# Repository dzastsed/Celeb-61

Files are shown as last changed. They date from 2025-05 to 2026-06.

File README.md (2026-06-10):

# Celeb-61 
*a nod towards Celeb-17 nickname of Makise Kurisu*

{D4E6624E-90EE-470E-BB59-F3589989F7F6}

Working beta version with 2025-05 board design. No more bodges!
# DISCLAIMER
This design is still a prototype, stuff may break and/or change. You've been warned.

## New features:

* usb-c to ttl adapter (optional)

* usb-c power supply (optional)

* better layout

* mounting screw holes

Preview pics 

{12444C88-0332-4251-8D5A-DB2188448844}

Bottom

{63C3DD92-8271-487E-8219-108E031BC739}

Top



Top, artwork edition (legacy design in `old project and gerbers (do not use)` folder)

# Schematic

{0ACC69AB-D940-442C-9313-E54FB51414F8}

# Firmware

Regular clock, and clock with scrambling code implemented are included `firmware` folder.

- Regular firmware:
Just does the clock function, and nothing more. It probably isn't even up to date with current board design. Not recommended to use.

- Scramlin' firmware:
Does character scramble every hour (after 30 seconds pass at 31 minute mark) to prevent cathode poisoning. Up to date. Use this firmware.

# Known issues

None so far?

# Setup guide

refer to [installation.md](https://github.com/dzastsed/Celeb-61/blob/main/installation.md)

# Parts list

refer to [parts.md](https://github.com/dzastsed/Celeb-61/blob/main/parts.md)

# Future improvements

ESP32 support - for wi-fi clock sync etc.

Diode on TTL module power rail to prevent powering it from secondary USB port (or complete removal of 2ndary USB port as this board can be powered by TTL module just fine).

Different board versions for different tube footprints.

A physical switch of some sort to turn the clock off while it's still plugged in

More covering for high voltage parts

# Credits

TheMobas0 - for help on making the scramble code

Greatsccott! - original board design

Elli - for drawing Makise Kurisu art

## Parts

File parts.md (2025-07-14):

# Parts list

Parts required for base model are: (links are NOT affiliate)

* Arduino pro mini clone - must be 5V 16mhz variant - I bought them from [here](https://www.aliexpress.com/item/32966475348.html)

   *note - there are a couple of versions with different footprint, make sure you get the one I used in this project.*

* 4x CD66 or CD61 nixie tubes

* 4x binary to decimal converter ICs (K155ID1, SN74141N and similar)

* 4x 20K 0.4W resistors

* 4x 0603 100nF capacitors

* 2x 0603 10uF capacitors

* High-voltage power supply capable of reaching 170v - I used [these](https://www.aliexpress.com/item/1005005994400583.html)

* 5V power supply capable of pushing roughly 2 amps. (10W total)

* DS1307 RTC - I purchased mine from [here](https://www.aliexpress.com/item/1005007091017702.html)

  *note - DS3231 module is also supported, but make sure you desolder one resistor (documented [here](https://lastminuteengineers.com/ds3231-rtc-arduino-tutorial/)) if you choose to use a non-rechargeable battery. I also recommend to use this one instead because it keeps the time better due to having an integrated thermometer.*

Optional extras but highly recommended:

* CH9340C TTL board - will allow easy reprogramming without soldering - I purchased mine [here](https://www.aliexpress.com/item/4001214247042.html)

* Type-C breakout board - I purchased mine [here](https://www.aliexpress.com/item/1005006846325447.html)

* A simple tactile switch - Used for easy chip reset, can be either harvested or simply purchased, I bought them [here](https://www.aliexpress.com/item/1005004159746274.html)

* M3 Motherboard standoff kit - Purely cosmetic, can be used together with another spare board to make a good platform to stand on. [link](https://www.aliexpress.com/item/1005007498157463.html)

* 16 pin socket - HIGHLY recommended, because bin2dec converters can be faulty and it's really painful to desolder if that's the case. [link](https://www.aliexpress.com/item/1005003744699628.html)

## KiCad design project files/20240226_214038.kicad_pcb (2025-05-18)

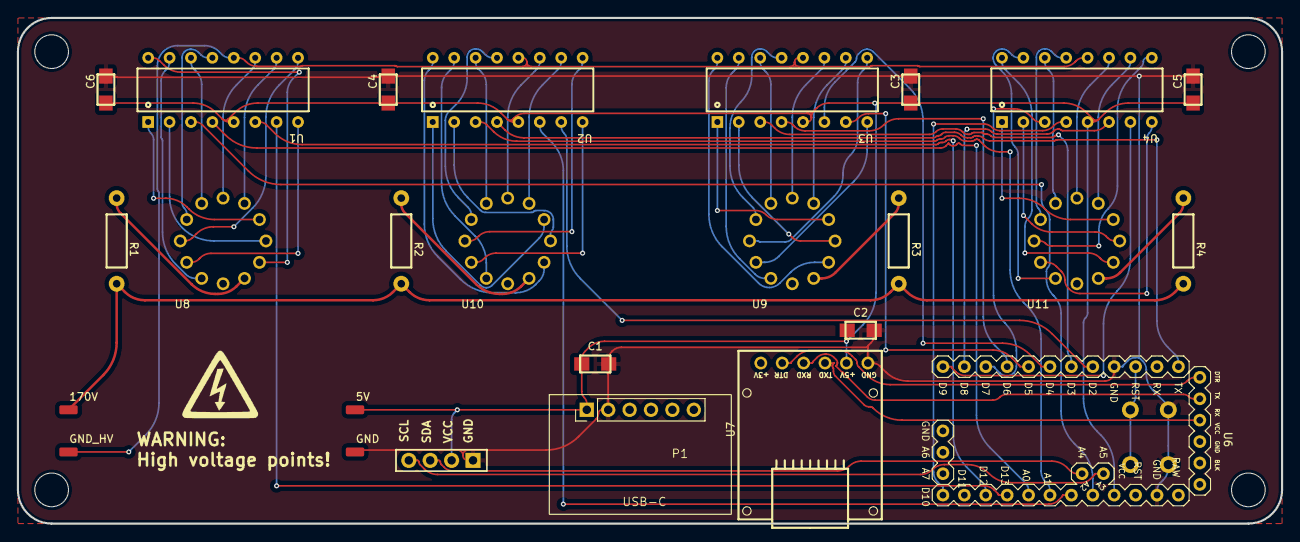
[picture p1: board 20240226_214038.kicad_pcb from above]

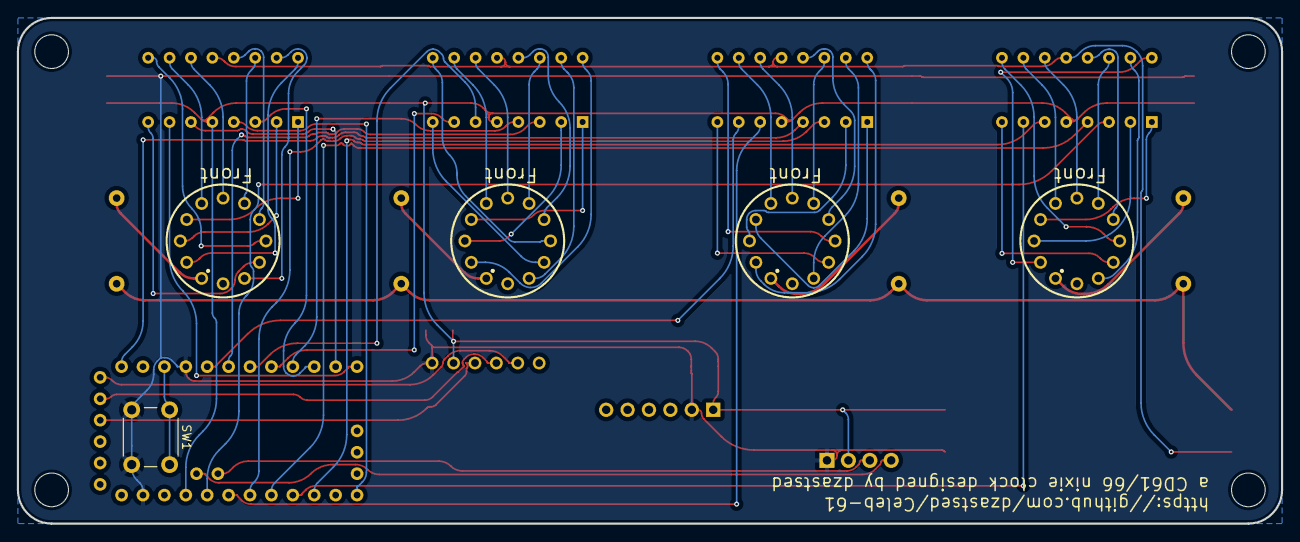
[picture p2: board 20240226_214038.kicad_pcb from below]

Board: 2 copper layers, 150.0 x 60.0 mm, 27 parts (5 on the bottom side), 70 nets.

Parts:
5V: 5V; SOLDERPAD
170V: 170V; SOLDERPAD
C1, C2: 10uF; CAPACITOR-SMD-1206
C3, C4, C5, C6: 100nF; CAPACITOR-SMD-1206
CLK1: ZS_042/DS3231; ZS-042-DS3231
GND: GND; SOLDERPAD
GND_HV: GND_HV; SOLDERPAD
P1: USB_C_Plug_USB2.0; USBC breakout
R1, R2, R3, R4: 20k; AXIAL-0.4
SW1: SW_Push; SW_PUSH_6mm
U1, U2, U3, U4: K155ID1/SN74141; DIP16
U6: ARDUINO PRO-MINI COPY; ARDUINOPROMINI_ARDUINO_PRO_MINI
U7: USB_TO_TTL_CH340E
U8, U9, U10, U11: Nixie_Tube_CD66_Tomas5054; NEC_NIXIE_TUBE_CD66A_TOMAS5054

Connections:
170v: 170V.1, R1.2, R2.2, R3.2, R4.2
+5V: 5V.1, C1.1, C2.1, C3.2, C4.2, C5.2, C6.2, CLK1.3 (VCC), P1.1 (VBUS), U1.5 (VCC), U2.5 (VCC), U3.5 (VCC), U4.5 (VCC), U6.VCC, U7.5 (+5V)
A1: U3.3 (A), U6.D3
A2: U4.3 (A), U6.D7
A3: U1.3 (A), U6.A3
A4: U2.3 (A), U6.A1
B1: U3.6 (B), U6.D4
B2: U4.6 (B), U6.D8
B3: U1.6 (B), U6.D12
B4: U2.6 (B), U6.A2
C1: U3.7 (C), U6.D5
C2: U4.7 (C), U6.D9
C3: U1.7 (C), U6.D13
C4: U2.7 (C), U6.D2
D1: U3.4 (D), U6.D6
D2: U4.4 (D), U6.D10
D3: U1.4 (D), U6.A0
D4: U2.4 (D), U6.TX
GND: C1.2, C2.2, C3.1, C4.1, C5.1, C6.1, CLK1.4 (GND), GND.1, P1.2 (GND), SW1.2, U6.GND, U6.GND@1 (GND), U7.6 (GND)
GND_HV: GND_HV.1, U1.12 (GND), U2.12 (GND), U3.12 (GND), U4.12 (GND)
unnamed: R1.1, U8.A
unnamed: R2.1, U10.A
unnamed: R3.1, U9.A
unnamed: R4.1, U11.A
unnamed: SW1.1, U6.RST@1 (RST)
unnamed: U6.RX@1 (RXI), U7.4 (TXD)
unnamed: U6.TX@1 (TX0), U7.3 (RXD)
unnamed: U6.DTR, U7.2 (DTR)
SCL: CLK1.1 (SCL), U6.A5
SDA: CLK1.2 (SDA), U6.A4
U8-0: U1.16 (0), U8.(.) (K(.))
U8-1: U1.15 (1), U8.1 (K(1))
U8-2: U1.8 (2), U8.2 (K(2))
U8-3: U1.9 (3), U8.3 (K(3))
U8-4: U1.13 (4), U8.4 (K(4))
U8-5: U1.14 (5), U8.5 (K(5))
U8-6: U1.11 (6), U8.6 (K(6))
U8-7: U1.10 (7), U8.7 (K(7))
U8-8: U1.1 (8), U8.8 (K(8))
U8-9: U1.2 (9), U8.9 (K(9))
U9-0: U3.16 (0), U9.(.) (K(.))
U9-1: U3.15 (1), U9.1 (K(1))
U9-2: U3.8 (2), U9.2 (K(2))
U9-3: U3.9 (3), U9.3 (K(3))
U9-4: U3.13 (4), U9.4 (K(4))
U9-5: U3.14 (5), U9.5 (K(5))
U9-6: U3.11 (6), U9.6 (K(6))
U9-7: U3.10 (7), U9.7 (K(7))
U9-8: U3.1 (8), U9.8 (K(8))
U9-9: U3.2 (9), U9.9 (K(9))
U10-0: U2.16 (0), U10.(.) (K(.))
U10-1: U2.15 (1), U10.1 (K(1))
U10-2: U2.8 (2), U10.2 (K(2))
U10-3: U2.9 (3), U10.3 (K(3))
U10-4: U2.13 (4), U10.4 (K(4))
U10-5: U2.14 (5), U10.5 (K(5))
U10-6: U2.11 (6), U10.6 (K(6))
U10-7: U2.10 (7), U10.7 (K(7))
U10-8: U2.1 (8), U10.8 (K(8))
U10-9: U2.2 (9), U10.9 (K(9))
U11-0: U4.16 (0), U11.(.) (K(.))
U11-1: U4.15 (1), U11.1 (K(1))
U11-2: U4.8 (2), U11.2 (K(2))
U11-3: U4.9 (3), U11.3 (K(3))
U11-4: U4.13 (4), U11.4 (K(4))
U11-5: U4.14 (5), U11.5 (K(5))
U11-6: U4.11 (6), U11.6 (K(6))
U11-7: U4.10 (7), U11.7 (K(7))
U11-8: U4.1 (8), U11.8 (K(8))
U11-9: U4.2 (9), U11.9 (K(9))

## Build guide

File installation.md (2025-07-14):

# Installation guide

## Hardware
First of all, order PCB from any PCB service you like. I used JLCPCB, their default settings worked fine. Gerber is in `gerber` folder.

After you get the PCBs, solder in all parts. A couple of reccomendations:

ALWAYS use flux. There will never be too much of it. 

Leave nixie tubes for the end. First solder everything else, and write the firmware. Then insert each tube individually, and turn the clock on without soldering them in to test.

## Software
After successfuly soldering everything in, flash the `NixieClock-Scramblin` firmware. In arduino setup select `Arduino Pro or Pro mini` board and upload the firmware.

Now check and see if every single segment shows up correctly in bootup sequence. If everything is right, go to the next step: 

Flash [this](https://github.com/MajicDesigns/MD_DS1307/tree/master/examples/MD_DS1307_Test) firmware, then open up Serial Monitor, set baudrate to 57600 bps, and write in the current clock (refer to the guide that gets printed out.) Make sure you have inserted the RTC battery, otherwise time will be lost upon power loss again.

After successfully setting up and verifying the time, flash `NixieClock-Scramblin` firmware back. And that's it! Clock is now ready for use!

## Post-setup

I highly recommend soldering in the top-side reset button as well, in previous design Arduino board liked to hang on startup for no reason, and this is a safe and easy way to restart it. This also allows easy resetting for tests.

I also recommend using screw standoffs or anything really and repurposing 2nd board to use it as a base to stand on.

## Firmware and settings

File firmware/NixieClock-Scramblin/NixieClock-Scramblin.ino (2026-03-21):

#include <MD_DS1307.h>
#include <Wire.h>
#include <math.h>
#include <stdlib.h>

#define A4 3
#define B4 4
#define C4 5
#define D4 6
#define A1 7
#define B1 8
#define C1 9
#define D1 10
#define A2 17
#define B2 12
#define C2 13
#define D2 14
#define A3 15
#define B3 16
#define C3 2
#define D3 1

char A[4] = {A1, A2, A3, A4};
char B[4] = {B1, B2, B3, B4};
char C[4] = {C1, C2, C3, C4};
char D[4] = {D1, D2, D3, D4};

int zero;
int one;
int two;
int three;
int hour;
int minute;
int second;
int scrambleCounter = 0;
bool scrambleActive = false;
unsigned long previousTime = 0;
const unsigned long interval = 1000; // Delay interval in milliseconds

// --- FUNCTION PROTOTYPES ---
int calculateDST(int d, int m, int y, int h);
void writenumber(int a, int b);
void tubeScramble(int timeInSeconds);
void off(int a);

void setup() {
  pinMode(A1, OUTPUT);
  pinMode(B1, OUTPUT);
  pinMode(C1, OUTPUT);
  pinMode(D1, OUTPUT);
  pinMode(A2, OUTPUT);
  pinMode(B2, OUTPUT);
  pinMode(C2, OUTPUT);
  pinMode(D2, OUTPUT);
  pinMode(A3, OUTPUT);
  pinMode(B3, OUTPUT);
  pinMode(C3, OUTPUT);
  pinMode(D3, OUTPUT);
  pinMode(A4, OUTPUT);
  pinMode(B4, OUTPUT);
  pinMode(C4, OUTPUT);
  pinMode(D4, OUTPUT);
  
  for (char i = 0; i < 4; i++) {
    digitalWrite(A[i], HIGH);
    digitalWrite(B[i], HIGH);
    digitalWrite(C[i], HIGH);
    digitalWrite(D[i], HIGH);
  }

  if (!RTC.isRunning())
    RTC.control(DS1307_CLOCK_HALT, DS1307_OFF);
  
  tubeScramble(30);
}

void loop() {
  RTC.readTime();
  
  // Get raw time from RTC (Standard Time)
  int rawHour = RTC.h;
  int currentDay = RTC.dd;
  int currentMonth = RTC.mm;
  int currentYear = RTC.yyyy; // Ensure your library returns full year (e.g. 2024), if not add 2000
  
  // Calculate adjusted hour
  hour = calculateDST(currentDay, currentMonth, currentYear, rawHour);
  minute = RTC.m;
  second = RTC.s;

  // Handle Overflow (if DST makes 23:00 -> 24:00, wrap to 00:00)
  if (hour >= 24) {
    hour = hour - 24;
  }

  unsigned long currentTime = millis();
  if (currentTime - previousTime >= interval) {
    previousTime = currentTime;

    // Check if it's time for a character scramble
    // Added check to ensure we only scramble once per hour
    if (minute == 31 && second == 30 && !scrambleActive) {
      scrambleActive = true;
      tubeScramble(30);
      scrambleActive = false;
    }

    // Display the time or scrambled characters
    if (!scrambleActive) {
      zero = (hour / 10) % 10;
      one = hour % 10;
      two =  (minute / 10) % 10;
      three = minute % 10;
    } else {
      // Perform the Nixie tube scramble
      tubeScramble(30);
    }

    writenumber(1, zero);
    writenumber(2, one);
    writenumber(3, two);
    writenumber(0, three);
  }
}

// --- DST CALCULATION FUNCTION ---
// Returns the hour + 1 if DST is active, otherwise returns original hour
int calculateDST(int d, int m, int y, int h) {
  // DST in Europe/Lithuania:
  // Starts: Last Sunday of March at 03:00 (Clocks go forward to 04:00)
  // Ends: Last Sunday of October at 04:00 (Clocks go back to 03:00)
  
  // If month is Jan, Feb, Nov, Dec -> Standard Time (Winter)
  if (m < 3 || m > 10) return h; 

  // If month is Apr, May, Jun, Jul, Aug, Sep -> DST (Summer)
  if (m > 3 && m < 10) return h + 1; 

  // Calculation for March and October
  // We need to find the previous Sunday.
  // This formula finds the date of the last Sunday of the current month
  int previousSunday = d - (RTC.dow - 1); // dow: 1=Sun, ... 7=Sat. Check your library if Sunday is 0 or 1.
  // MD_DS1307 usually uses 1=Sunday. If calculation seems off, check if library returns 0 for Sunday.
  
  // But a simpler way for "Last Sunday" rule:
  // The last Sunday in a month with 31 days (Mar, Oct) falls on:
  // 31-(dow of last day).
  // Formula to get day of week for specific date is complex, so we approximate:
  
  // Standard approximation for EU DST:
  // DST starts last Sun March, ends last Sun Oct.
  
  int previousSundayDay = d - RTC.dow + 1; // Assuming RTC.dow returns 1 for Sunday.
  if(RTC.dow == 1) previousSundayDay = d; 

  // MARCH: DST starts on last Sunday at 03:00
  if (m == 3) {
      // Calculate date of last Sunday in March
      // (31 - (5 * y / 4 + 4) % 7) is a common formula for March last sunday
      int lastSunday = 31 - (5 * y / 4 + 4) % 7;
      
      if (d > lastSunday) return h + 1;
      if (d < lastSunday) return h;
      // If it IS the last Sunday
      if (h >= 3) return h + 1; // After 3am, add hour
      return h;
  }

  // OCTOBER: DST ends on last Sunday at 04:00 (Standard time 3am)
  if (m == 10) {
      // Calculate date of last Sunday in October
      int lastSunday = 31 - (5 * y / 4 + 1) % 7;
      
      if (d > lastSunday) return h; // Back to winter time
      if (d < lastSunday) return h + 1; // Still summer time
      // If it IS the last Sunday
      if (h < 3) return h + 1; // Before 3am UTC (which is 4am Summer time), still add hour
      return h;
  }

  return h;
}

void writenumber(int a, int b) {
  switch (b) {
    case 0:
      digitalWrite(A[a], LOW);
      digitalWrite(B[a], LOW);
      digitalWrite(C[a], LOW);
      digitalWrite(D[a], LOW);
      break;
    case 9:
      digitalWrite(A[a], HIGH);
      digitalWrite(B[a], LOW);
      digitalWrite(C[a], LOW);
      digitalWrite(D[a], HIGH);
      break;
    case 8:    
      digitalWrite(A[a], LOW);
      digitalWrite(B[a], LOW);
      digitalWrite(C[a], LOW);
      digitalWrite(D[a], HIGH);      
      break;
    case 7:
      digitalWrite(A[a], HIGH);
      digitalWrite(B[a], HIGH);
      digitalWrite(C[a], HIGH);
      digitalWrite(D[a], LOW);      
      break;
    case 6:
      digitalWrite(A[a], LOW);
      digitalWrite(B[a], HIGH);
      digitalWrite(C[a], HIGH);
      digitalWrite(D[a], LOW);  
      break;
    case 5:
      digitalWrite(A[a], HIGH);
      digitalWrite(B[a], LOW);
      digitalWrite(C[a], HIGH);
      digitalWrite(D[a], LOW);
      break;
    case 4:
      digitalWrite(A[a], LOW);
      digitalWrite(B[a], LOW);
      digitalWrite(C[a], HIGH);
      digitalWrite(D[a], LOW);
      break;
    case 3:
      digitalWrite(A[a], HIGH);
      digitalWrite(B[a], HIGH);
      digitalWrite(C[a], LOW);
      digitalWrite(D[a], LOW);
      break;
    case 2:
      digitalWrite(A[a], LOW);
      digitalWrite(B[a], HIGH);
      digitalWrite(C[a], LOW);
      digitalWrite(D[a], LOW);
      break;
    case 1:
      digitalWrite(A[a], HIGH);
      digitalWrite(B[a], LOW);
      digitalWrite(C[a], LOW);
      digitalWrite(D[a], LOW);      
      break;
  }
}

void tubeScramble(int timeInSeconds) {
  int n1 = round(sqrt((2 * timeInSeconds)/0.001));
  int n2 = 0;
  
  while (n1 > 0) {
    writenumber(1, n2 % 10);
    writenumber(2, n2 % 10);
    writenumber(3, n2 % 10);
    writenumber(0, n2 % 10);
    
    n1--;
    n2++;
    delay(n1);
  }
}

void off(int a) {
  digitalWrite(A[a], HIGH);
  digitalWrite(B[a], HIGH);
  digitalWrite(C[a], HIGH);
  digitalWrite(D[a], HIGH);
}

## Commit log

2024-05-01 project and gerber file
2024-05-01 gerber with artwork
2025-05-18 latest project as of this moment
    [20240226_214038.kicad_pcb, 20240226_214038.kicad_sch]
2025-07-14 Delete nixiev2 directory
    rework of repo
    [20240226_214038.kicad_pcb, 20240226_214038.kicad_sch]
2025-07-14 latest project
    [20240226_214038.kicad_pcb, 20240226_214038.kicad_sch]
